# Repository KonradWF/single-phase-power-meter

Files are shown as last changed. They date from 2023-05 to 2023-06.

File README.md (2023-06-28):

# Single-Phase power meter!

The device is used to measure electric power from a single-phase electrical grid.
The following electrical network parameters can be measured with the device:
* Voltage V
* Current I
* Power P
* Reactive Power Q
* Apparent Power S
* Power Factor PF

## Authors 
- Konrad Fiałkowski
- Michał Krzyworzeka
- Bartłomiej Paluch

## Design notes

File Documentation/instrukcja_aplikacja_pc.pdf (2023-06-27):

Metodyki projektowania i modelowania systemów 1 Instrukcja obsługi aplikacji PC MIERNIK MOCY I LICZNIK ENERGII Z KOMUNIKACJĄ USB

Po uruchomieniu aplikacji odtworzy się okienko przedstawione poniżej na rysunku 1. W chwili, gdy aplikacja nie jest połączona z urządzeniem, przy mierzonych parametrach zostanie ukazany napis „b/d”, który wskaże, że nie zostały dostarczone żadne dane. W tym samym czasie na wykresie mocy od czasu pokazywana będzie wartość 0 W.

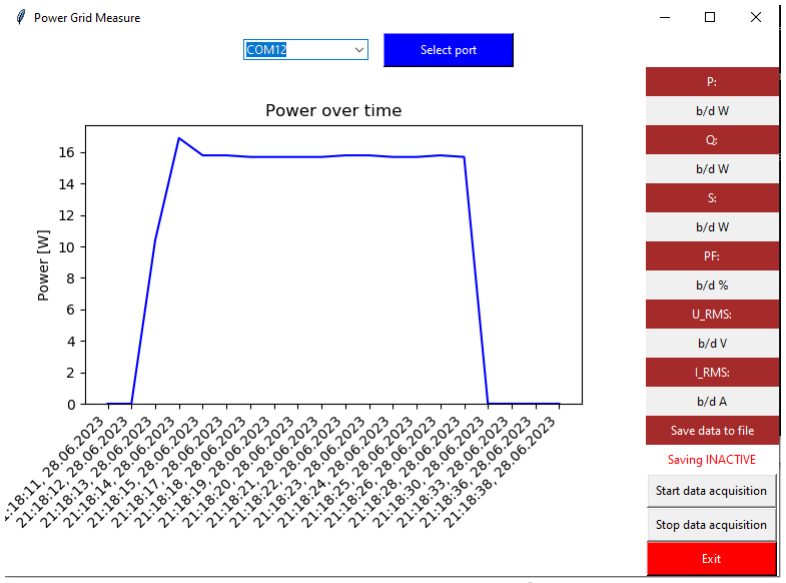
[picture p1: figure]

W celu połączenia aplikacji z urządzeniem, należy wybrać w okienku wyboru w górnej części aplikacji odpowiedni port z listy (przedstawiona na rysunku 2.), do którego podpięty jest miernik mocy. Oznaczenie portu w systemie Windows można sprawdzić w Menedżerze urządzeń w zakładce Porty (COM i LPT). Po wybraniu portu, należy wcisnąć niebieski przycisk „Select port”.

Rysunek 2. Okienko
wyboru portów.

Rysunek 1. Okienko aplikacji po uruchomieniu - brak połączenia z urządzeniem.

Po połączeniu aplikacji z miernikiem, w prawej części zostaną wyświetlone mierzone parametry. Na wykresie mocy czynnej od czasu będzie wykreślana ta zależność. Okienko aplikacji po podłączeniu do urządzenia zostało ukazane na rysunku 3.

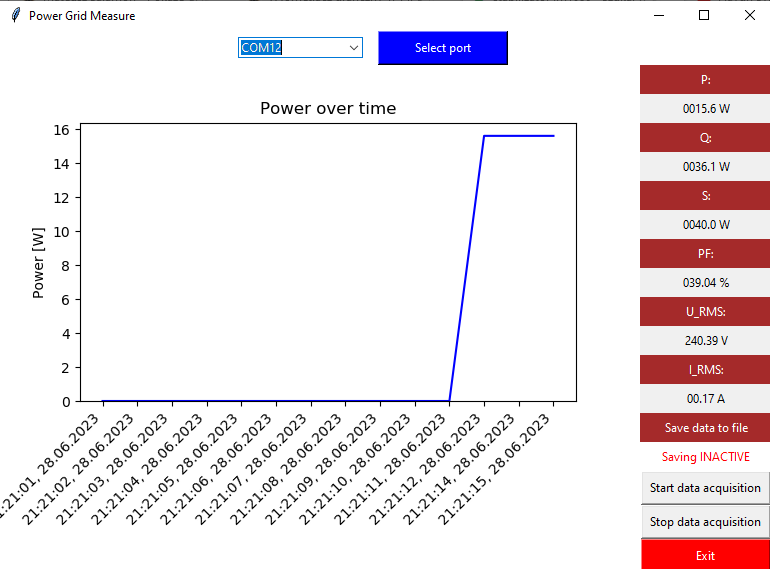
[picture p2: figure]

Rysunek 3. Okienko aplikacji po połączeniu z miernikiem mocy.

Mierzone dane można zapisać do pliku. W tym celu należy wcisnąć przycisk „Start data acquisition” – powyżej czerwony napis „Saving INACTIVE” (jak na rysunku 3.) powinien zamienić się na zielony napis „Saving ACTIVE” (przedstawiony na rysunku 4.).
Po wciśnięciu przycisku „Start data acquisition” utworzy się nowy plik z datą rozpoczęcia zapisu mierzonych parametrów. By przerwać zapis danych do pliku, należy wcisnąć przycisk „Stop data acquisition” – pojawi się z powrotem czerwony napis „Saving INACTIVE”.

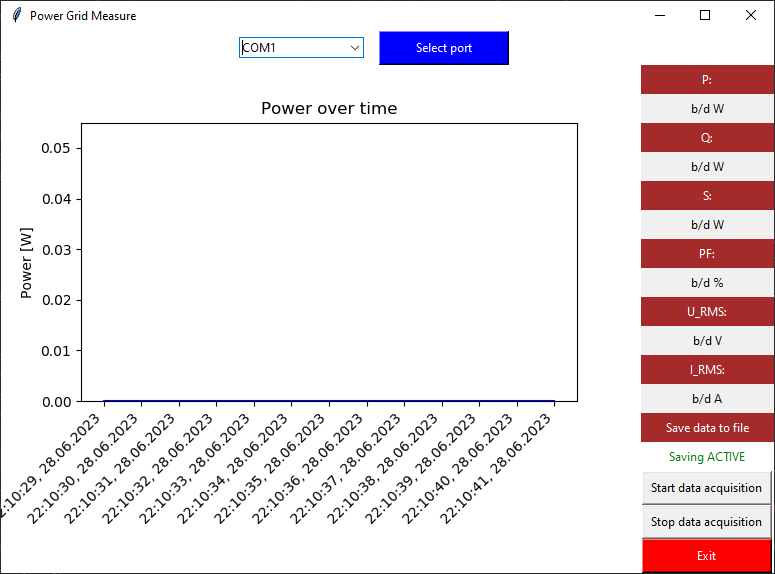
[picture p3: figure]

Rysunek 4. Zapis mierzonych parametrów do pliku - informacja o zapisie.

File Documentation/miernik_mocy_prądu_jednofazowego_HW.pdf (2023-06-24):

Metodyki projektowania i modelowania systemów 1 Dokumentacja projektu - hardware MIERNIK MOCY I LICZNIK ENERGII Z KOMUNIKACJĄ USB

1) Założenia funkcjonalne projektu:

Urządzenie ma umożliwić pomiar wejściowych wielkości elektrycznych urządzeń zasilanych z jednofazowej sieci elektroenergetycznej o napięciu skutecznym 230V.
Dzięki komunikacji USB wyniki pomiarów mogą być zapisywane i przetwarzane na komputerze.
2) Rozeznanie rynku rozwiązań komercyjnych – ceny i funkcjonalność:

Na rynku dostępne są urządzenia o podobnej funkcjonalności do zastosowań laboratoryjnych, przemysłowych jaki i domowych.
W przypadku urządzeń dedykowanych gospodarstwom domowym, mających zwykle postać nakładki na gniazdo funkcjami są pomiar napięcia, prądu, mocy, energii, czasem także częstotliwości i współczynnika mocy (cosφ). Deklarowana dokładność pomiaru to 1%, a maksymalna moc mierzona to 3,6kW. Koszty takich urządzeń zaczynają się od około 60zł.
Urządzenia dla przemysłu mają postać modułów do montażu w rozdzielniach na szynach DIN lub są przystosowane do zabudowy na panelach sterowania lub drzwiach szaf sterowniczych. Funkcjonalność jest podobna jak w przypadku produktów dla gospodarstw domowych, ale zakres pomiaru zwykle jest szerszy, występują też urządzenia przystosowane do współpracy z siecią trójfazową. Koszty najprostszych rozwiązań są podobne jak w przypadku mierników dla gospodarstw domowych.
Kolejną grupą są przyrządy laboratoryjne, oferujące porównywalne
z przemysłowymi zakresy pomiarowe, ale znacznie wyższą dokładność sięgającą 0,1%. Ceny tych urządzeń zaczynają się od kilkuset złotych.
3) Koncepcja rozwiązania:
a) parametry:
- Zakres pomiaru napięcia – 0-230VAC (jeśli zasilanie z innego źródła)
- Zakres pomiaru napięcia – 230VAC±10% (jeśli zasilanie z mierzonego źródła)
- Zakres pomiaru prądu – 0-10AAC
- Pomiar mocy, energii oraz współczynnika mocy
- Separacja galwaniczna zasilania i obwodów wejściowych od układu mikroprocesora
- wyświetlacz OLED
- komunikacja USB dodatkowo separowana dedykowanym układem

b) schemat blokowy

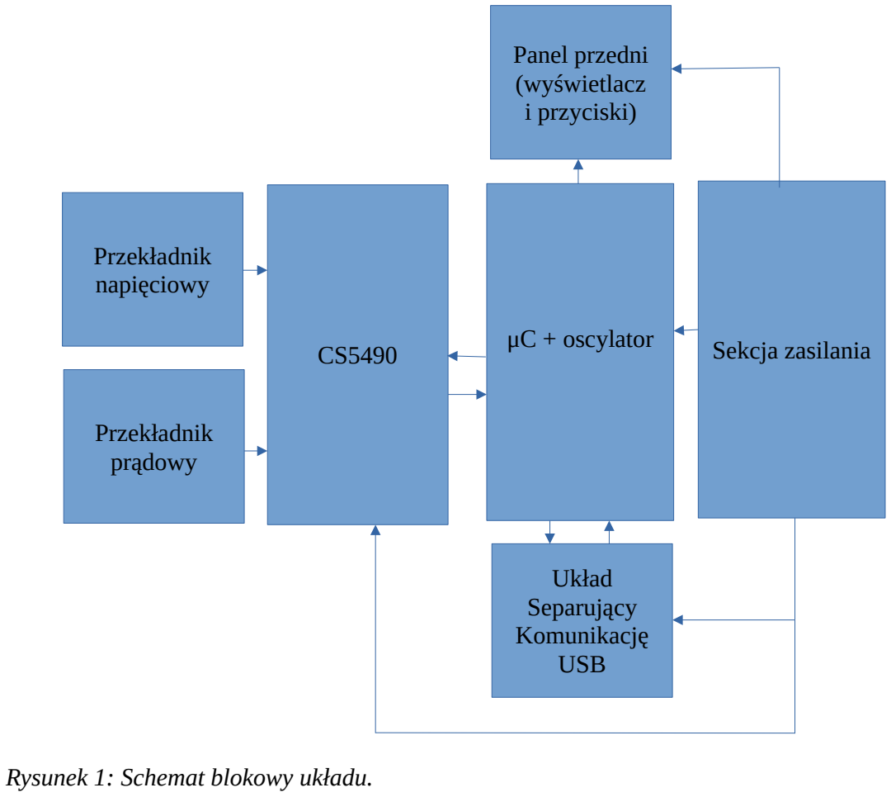
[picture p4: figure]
Rysunek 1: Schemat blokowy układu.; Przekładnik napięciowy; Przekładnik prądowy; Panel przedni (wyświetlacz i przyciski); Układ Separujący Komunikację USB; μC + oscylator; Sekcja zasilania

c) dobór elementów
- Przekładnik napięciowy
Został zastosowany przekładnik napięciowy w postaci transformatora
o przekładni 1:1 (TV19E firmy YHDC) i dzielnik rezystancyjny proponowany przez notę aplikacyjną układu do pomiaru mocy. Rozwiązanie takie zapewnia separacje galwaniczną.
- Przekładnik prądowy
Został zastosowany uniwersalny przekładnik prądowy 20A/0,1A (TAZ14-400 firmy YHDC) a do jego wyjścia został podłączony dzielnik rezystancyjny zapewniający nominalne obciążenie strony wtórnej przekładnika.
- Układ pomiaru mocy
Do pomiary mocy zastosowany został specjalizowany układ Cirrus Logic CS5490, który od strony wejściowej zostanie podłączony do przekładników prądowego i napięciowego przez odpowiednie dzielniki rezystancyjne
i pojemnościowe, a z mikrokontrolerem skomunikuje się przez UART.
- Układ separujący USB

Mimo, że przekładniki prądowe zapewniają separację galwaniczną od sieci dla dodatkowego bezpieczeństwa transmisja USB jest dodatkowo odseparowana galwanicznie, za pomocą układu ADUM3160.
- Wyświetlacz
Wyświetlacz nie jest konieczny do działania urządzenia, transmisja danych przez USB może być wystarczająca, ale zastosowanie ekranu może usprawnić prace z urządzeniem w pewnych sytuacjach. Ze względu na dostępność i optymalizację kosztową zastosowany został wyświetlacz GMT130-v0.1.
- Mikrokontroler
Mikrokontroler musiał spełnić następujące warunki:
-zasilanie 3,3V
-wbudowany RTC
-interface USB
-interface UART
-interface I²C
-interface SPI
-piny GPIO do podłączenia przycisków
Taką specyfikację spełnia kilka kontrolerów z rodziny ATXmega oraz STM32, ale ze względu na aktualną dostępność wybrano STM32F103C8T6
- Sekcja zasilania
Sekcja zasilania została oparta o transformator, w celu zapewnienia maksymalnego bezpieczeństwa i niezawodności układu jak również niskiego poziomu szumów w liniach zasilających. Obniżone napięcie jest prostowane pełnookresowo, odfiltrowane i stabilizowane regulatorem liniowym. Wybrano transformator sieciowy firmy Breve o oznaczeniu katalogowym TEZ6,0/D 230/7,5V.
Zastosowany jest stabilizator liniowy napięcia 3,3V, ze względu na pobór prądu elementów urządzenia jego wydajność prądowa musi wynosić co najmniej 500mA. Takie warunki z zapasem spełnił LM1086-3,3 firmy Texas Instruments.

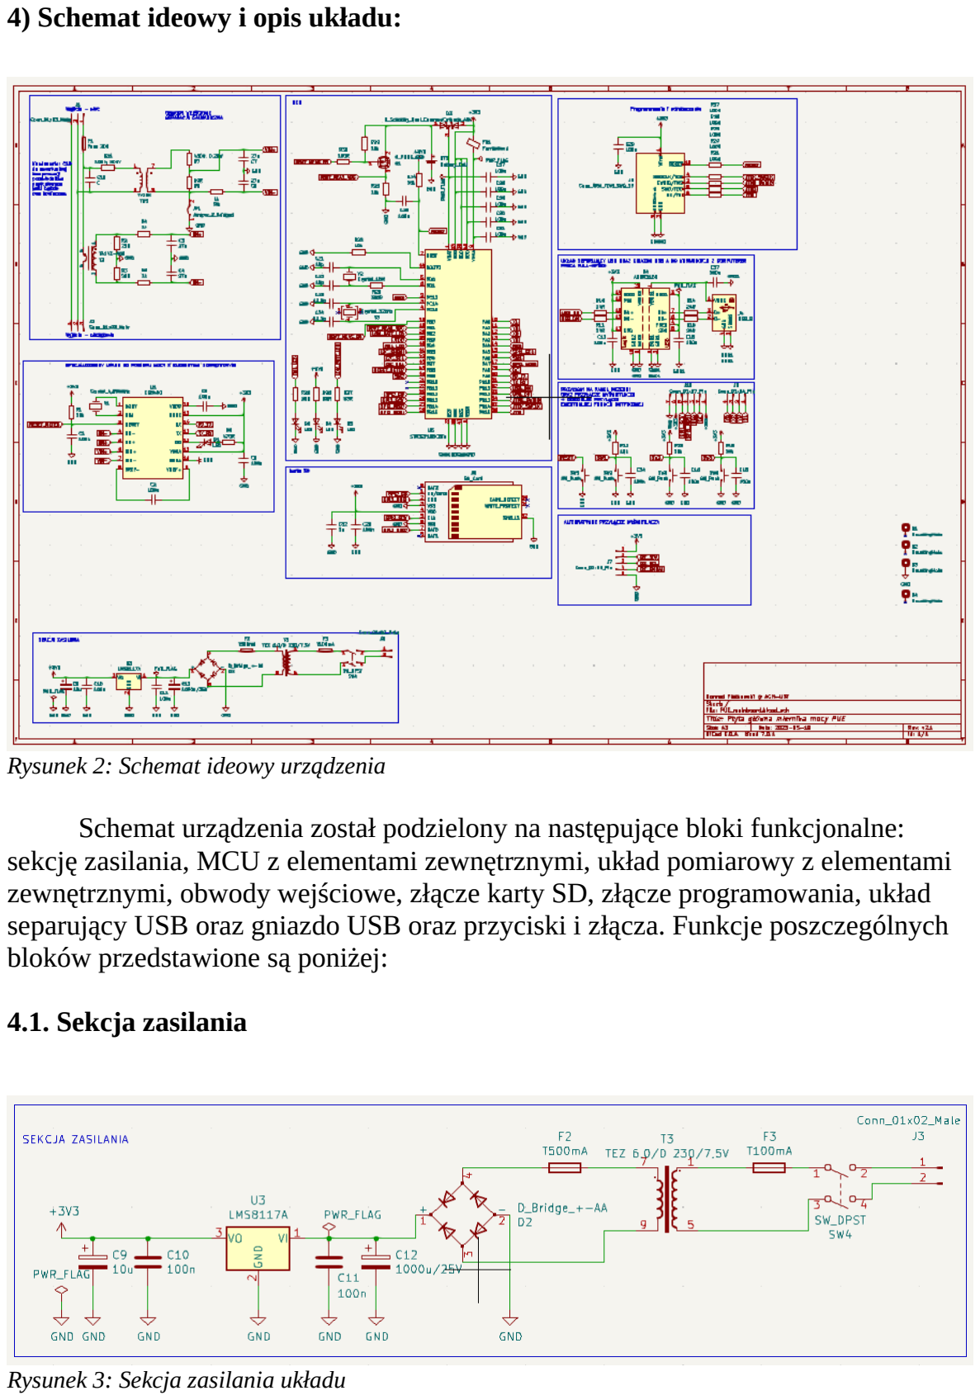
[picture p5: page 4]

4) Schemat ideowy i opis układu:

Schemat urządzenia został podzielony na następujące bloki funkcjonalne: sekcję zasilania, MCU z elementami zewnętrznymi, układ pomiarowy z elementami zewnętrznymi, obwody wejściowe, złącze karty SD, złącze programowania, układ separujący USB oraz gniazdo USB oraz przyciski i złącza. Funkcje poszczególnych bloków przedstawione są poniżej:

### 4.1. Sekcja zasilania

Rysunek 2: Schemat ideowy urządzenia

Rysunek 3: Sekcja zasilania układu

Zasilacz urządzenia jest przedstawieniowy na rysunku 3. Jest to typowy zasilacz transformatorowy z mostkiem Gretza i stabilizatorem liniowym. Zapewnia on separację galwaniczną, dużą niezawodność oraz niski poziom szumów. Dodatkowo takie rozwiązanie jest znacznie szybsze w projektowaniu niż przetwornica.

### 4.2. Obwody wejściowe

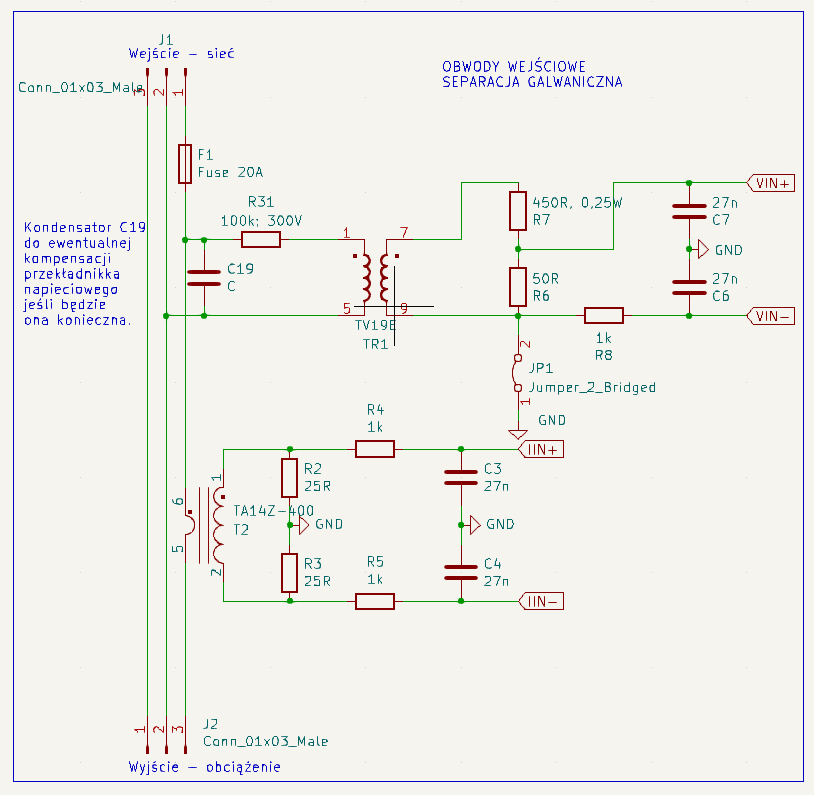
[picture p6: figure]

Obwody wejściowe (Rysunek 4) miernika wzorowane są na nocie katalogowej układu CS5490 i składają się z bezpiecznika, przekładników prądowego i napięciowego oraz zespołu dzielników napięć. Kondycjonowane za ich pomocą sygnały proporcjonalne do mierzonego prądu i napięcia są podawane bezpośrednio na wejścia układu CS5490.

Rysunek 4: Obwody wejściowe miernika

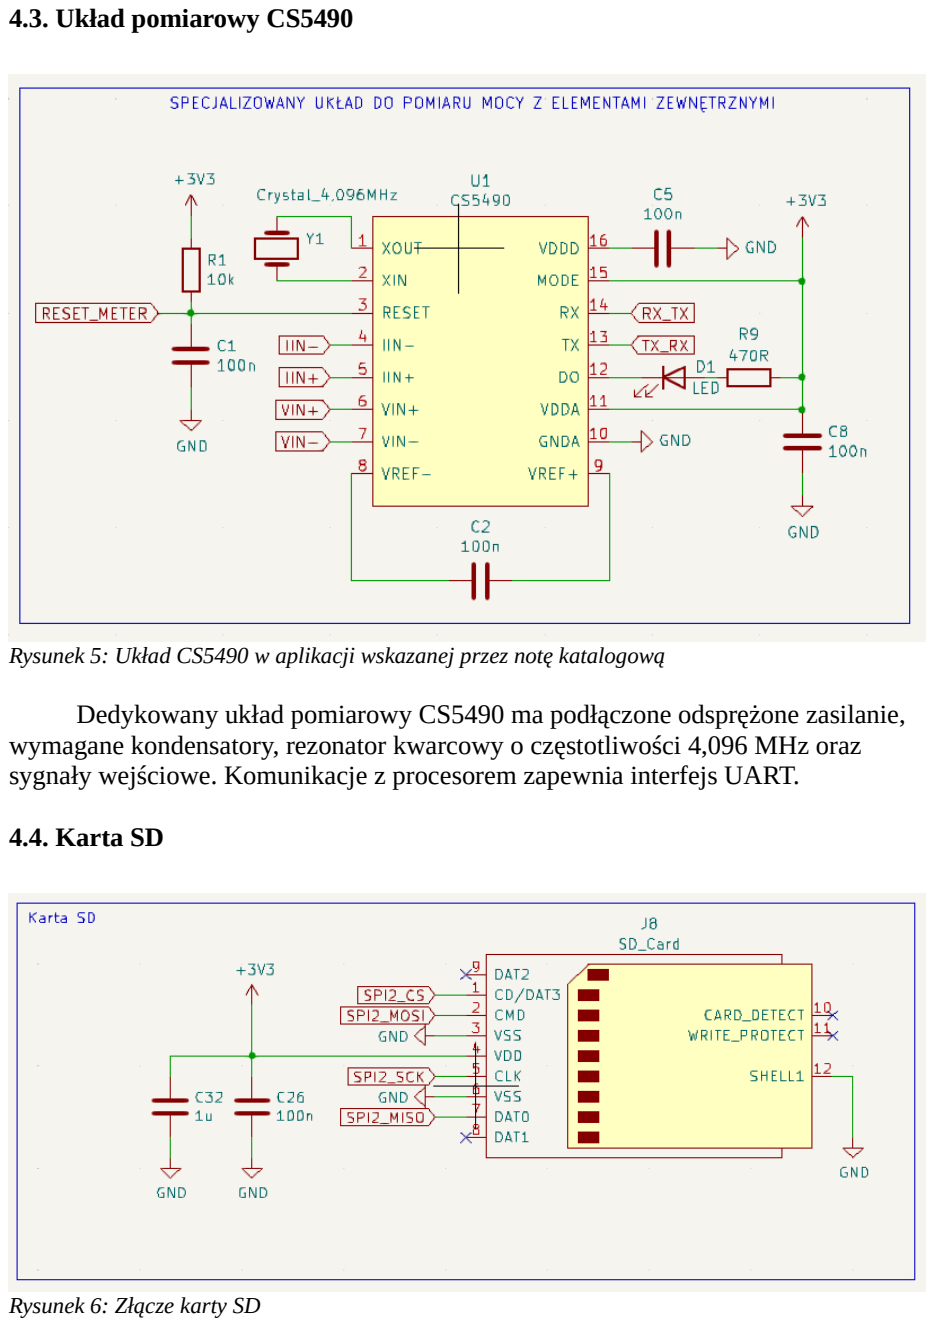
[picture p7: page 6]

### 4.3. Układ pomiarowy CS5490

Dedykowany układ pomiarowy CS5490 ma podłączone odsprężone zasilanie, wymagane kondensatory, rezonator kwarcowy o częstotliwości 4,096 MHz oraz sygnały wejściowe. Komunikacje z procesorem zapewnia interfejs UART.

### 4.4. Karta SD

Rysunek 5: Układ CS5490 w aplikacji wskazanej przez notę katalogową

Rysunek 6: Złącze karty SD

Przedstawione na Rysunku 6 złącze karty SD wraz z kondensatorami odsprzedającymi jej zasilanie umożliwia wykorzystanie urządzenia do akwizycji danych bez współpracy z komputerem.

### 4.5. Mikrokontroler i wymagane elementy zewnętrzne

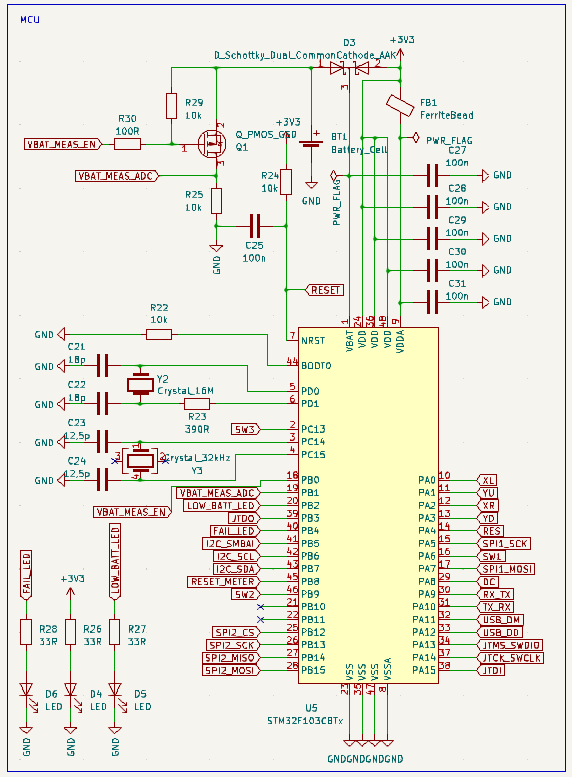
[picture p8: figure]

Rysunek 7: Mikrokontroler STM32F103C8T6, diody sygnalizacyjne oraz niezbędne elementy zewnętrzne

Pracą miernika steruje mikrokontroler STM32F103C8T6. Pracuje on z zewnętrznym rezonatorem kwarcowym 16 MHz. Zastosowano także rezonator 32,768 kHz potrzebny do pracy zegara czasu rzeczywistego stosowanego przy zapisywaniu parametrów sieci w czasie na kartę SD. Zegar czasu rzeczywistego ma podtrzymanie zapewniane przez baterię o napięciu 3 V. W tym bloku funkcjonalnym znajduje się też układ pozwalający na mierzenie napięcia tej baterii. Jest on załączany tranzystorem, co zapobiega rozładowywaniu baterii w czasie, gdy nie jest ona mierzona.

### 4.6. Złącze JTAG/SWD

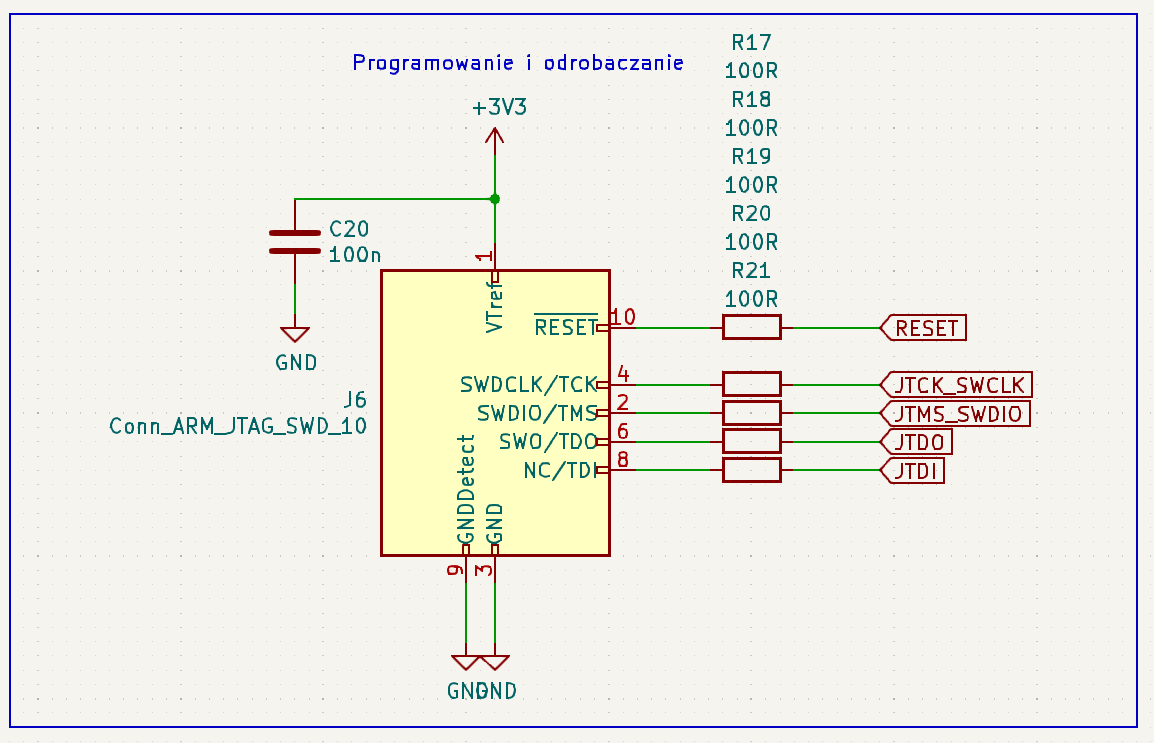
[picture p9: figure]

W celu zaprogramowania mikroprocesora w przyrządzie pomiarowym należy do złącza J6 (Rysunek 8) podłączyć programator zgodny ze standardem JTAG albo SWD. Linie zrgnałowe zostały zabezpieczone rezystorami o wartości 100 Ω co zmniejsza szanse uszkodzenia układu w przypadku użycia wadliwej przejściówki.

Rysunek 8: Złącze do programowania i debugowania kodu urządzenia.

### 4.7. Układ separujący komunikację USB

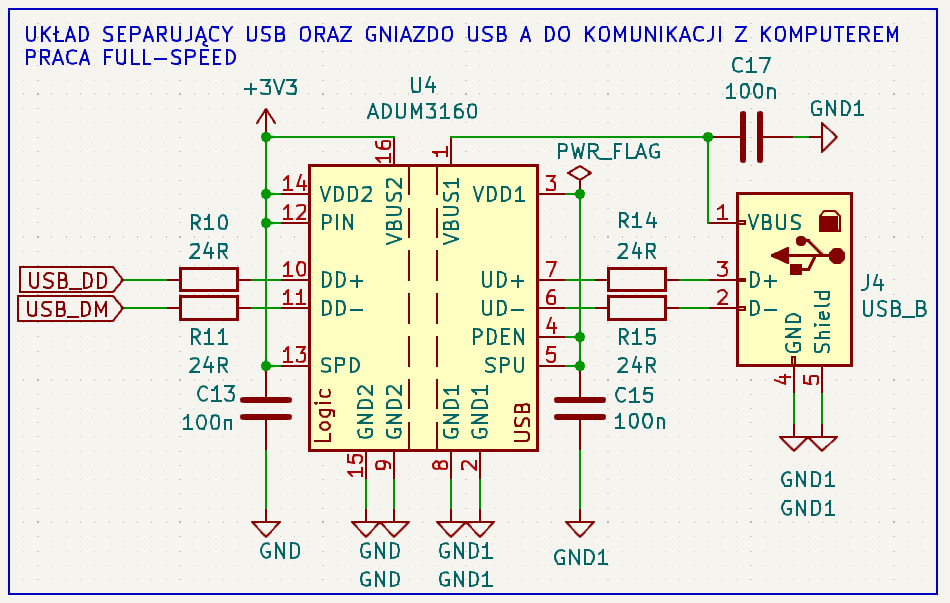
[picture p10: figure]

Aby zapewnić jak największe bezpieczeństwo użytkowania układu przy współpracy z komputerem PC komunikacja przez USB została odseparowana galwanicznie dedykowanym układem scalonym ADUM3160. Układ jest połączony w konfiguracji zalecanej przez notę katalogową.

### 4.8. Złącza i przyciski

Do obsługi urządzenia przeznaczone są cztery przyciski (jeden z nich to RESET, pozostałe służą od obsługi menu). Ponadto z płyty głównej wyprowadzone jest złącze magistrali SPI i zasilania do wyświetlacza, alternatywne złącze do ekranu z magistralą I²C i zasilaniem. Dodatkowo zostało wyprowadzone złącze do obsługi funkcji wyświetlacza dotykowego.

Rysunek 9: Układ separujący galwanicznie komunikację USB wraz z elementami zewnętrznymi.

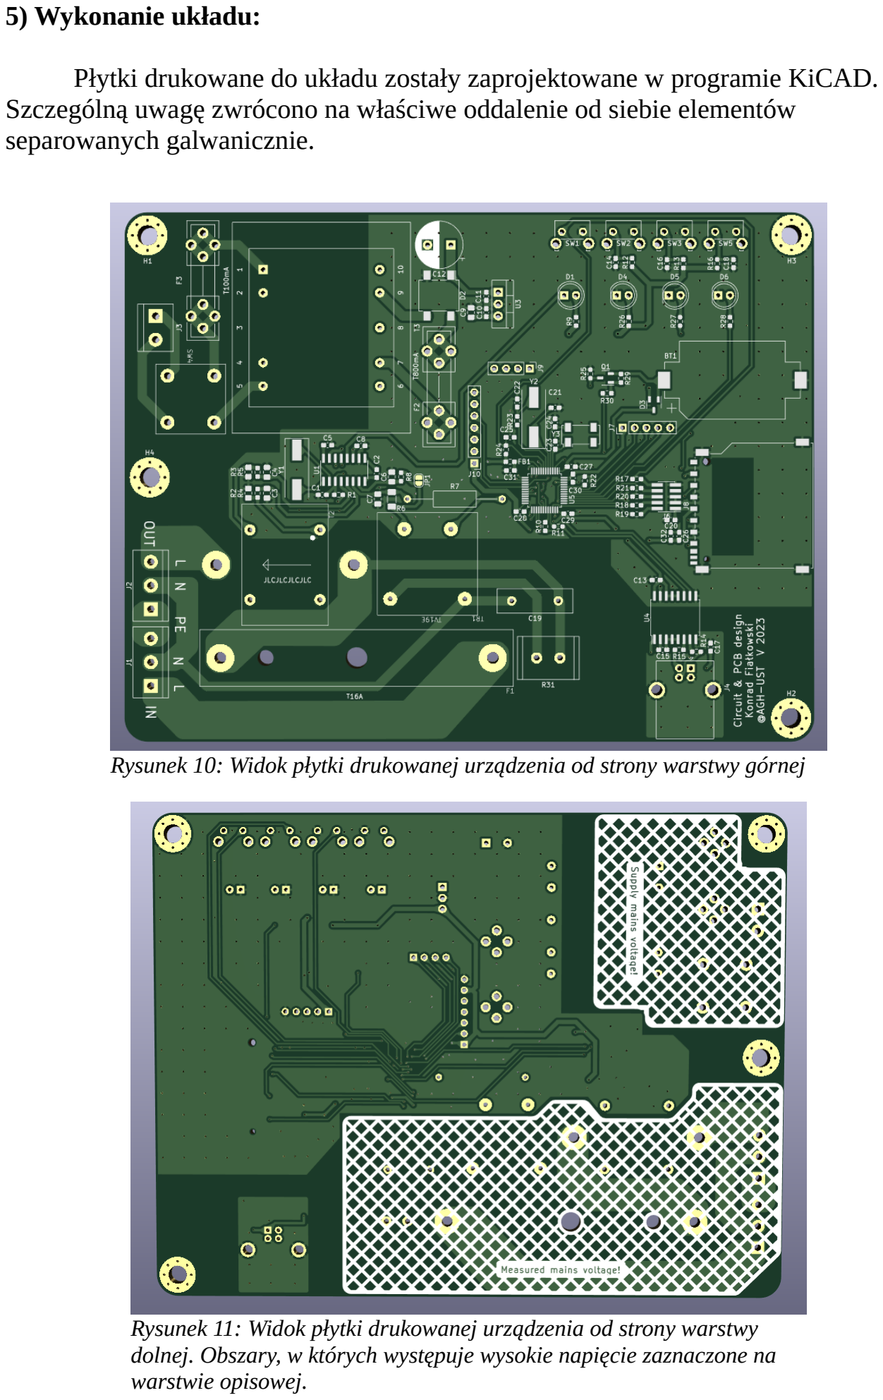
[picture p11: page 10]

5) Wykonanie układu:

Płytki drukowane do układu zostały zaprojektowane w programie KiCAD. Szczególną uwagę zwrócono na właściwe oddalenie od siebie elementów separowanych galwanicznie.

Rysunek 10: Widok płytki drukowanej urządzenia od strony warstwy górnej

Rysunek 11: Widok płytki drukowanej urządzenia od strony warstwy dolnej. Obszary, w których występuje wysokie napięcie zaznaczone na warstwie opisowej.

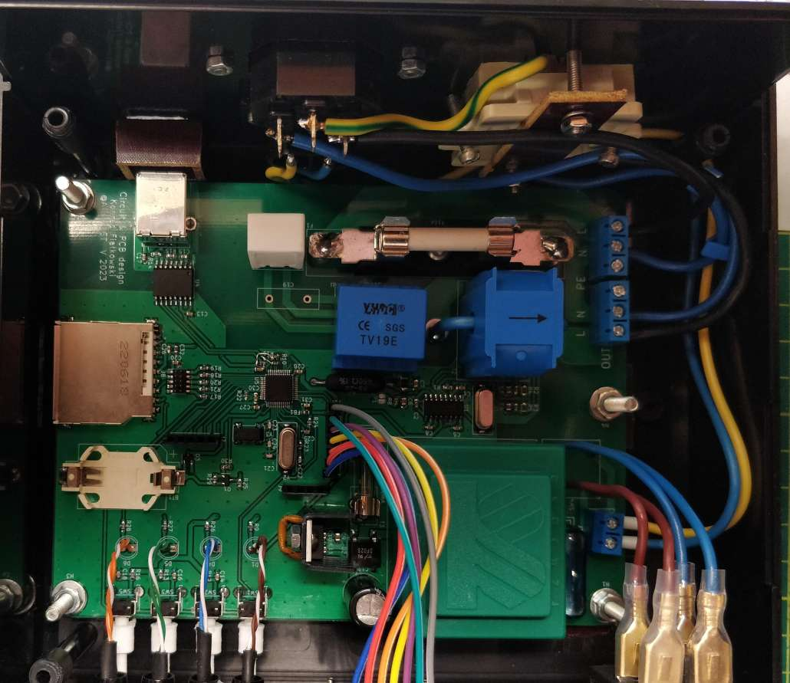
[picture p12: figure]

8) Podsumowanie :

Projekt urządzenia wykonano w oparciu o noty katalogowe zastosowanych układów scalonych, oraz opisy techniczne dostępnych komercyjnie przyrządów.
Po wgraniu odpowiedniego oprogramowania i współczynników kalibracyjnych układ działa poprawnie. W kolejnej rewizji można by opracować bardziej energooszczędny układ zasilania, ekranowanie toru pomiarowego oraz usunąć drobne wady zauważone podczas uruchamiania projektu.

Rysunek 12: Widok zmontowanej płytki drukowanej urządzenia zamontowanej w obudowie

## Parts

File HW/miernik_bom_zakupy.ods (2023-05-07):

Source: | D:\Elektronika\PUE_mainboard\PUE_mainboard.kicad_sch |  |  |  |  | czy zgodne z iloscią?
Date: | 14.04.2023 17:34:17
Tool: | Eeschema 7.0.1
Generator: | D:\KiCAD_7\7.0\bin\scripting\plugins/bom_csv_grouped_by_value.py
Component Count: | 98
Collated Components:
Item | Qty | Reference(s) | Value |  |  |  | DNP
1 | 1 | BT1 | Battery_Cell | https://www.tme.eu/pl/details/ch28-2032/baterie-pojemniki-i-uchwyty/comf/ch28-2032lf/ | https://www.mouser.pl/ProductDetail/Renata/SMTU2032-C?qs=UxeAxwACbqkmlMDdDbz%2FoA%3D%3D | x
2 | 20 | C1, C2, C5, C8, C10, C11, C13, C14, C15, C16, C17, C18, C20, C25, C26, C27, C28, C29, C30, C31 | 100n | https://www.tme.eu/pl/details/0603yc104kat2a/kondensatory-mlcc-smd/kyocera-avx/ | https://www.mouser.pl/ProductDetail/YAGEO/CC0603JRX7R8BB104?qs=5q%252BqlK8CmJTEpQNLR3WZPw%3D%3D | x
3 | 4 | C3, C4, C6, C7 | 27n | https://www.tme.eu/pl/details/c0603c273k5rac/kondensatory-mlcc-smd/kemet/c0603c273k5ractu/ | https://www.mouser.pl/ProductDetail/KEMET/C0805C273J3GACTU?qs=oww1zRtU%252Bv2SG5P1%2FHn6gQ%3D%3D | x
4 | 1 | C9 | 10u | https://www.tme.eu/pl/details/grm188z71a106ka73d/kondensatory-mlcc-smd/murata/ | https://www.mouser.pl/ProductDetail/Samsung-Electro-Mechanics/CL21B106KOQNNNE?qs=349EhDEZ59r8qgLddyW2Yw%3D%3D | x
5 | 1 | C12 | 1000u/25V | https://www.tme.eu/pl/details/ucd1e102mnq1ms/kondensatory-elektrolityczne-smd/nichicon/ | https://www.mouser.pl/ProductDetail/Panasonic/EEU-FR1E102E?qs=zR1FDKe%2FpuBUNZowDH12Tw%3D%3D | x
6 | 1 | C19 | C | nie montować
7 | 2 | C21, C22 | 18p | https://www.tme.eu/pl/details/vj0402a180jxjcw1bc/kondensatory-mlcc-smd/vishay/ | https://www.mouser.pl/ProductDetail/KYOCERA-AVX/02013A180GAT2A?qs=xoLhGqqHLYBbnRIqdpEZPg%3D%3D | x
8 | 2 | C23, C24 | 12,5p | https://www.tme.eu/pl/details/04025a120jat2a/kondensatory-mlcc-smd/kyocera-avx/ | https://www.mouser.pl/ProductDetail/Murata-Electronics/GCM1885C2A120GA16D?qs=QzBtWTOodeVSlFS21Kh%2F4w%3D%3D | x
9 | 1 | C32 | 1u | https://www.tme.eu/pl/details/c0603c105k3rac/kondensatory-mlcc-smd/kemet/c0603c105k3ractu/ | https://www.mouser.pl/ProductDetail/KYOCERA-AVX/0603YC105KAT2A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 | x
10 | 4 | D1, D4, D5, D6 | LED | https://www.tme.eu/pl/details/fyl-5013gd1c/diody-led-tht-okragle/foryard/ | https://www.mouser.pl/ProductDetail/Cree-LED/C566D-GFE-CY0Z0792?qs=7D1LtPJG0i2HFf%2FmrtSWoA%3D%3D | x
11 | 1 | D2 | D_Bridge_+-AA | mam w gratach
12 | 1 | D3 | D_Schottky_Dual_CommonCathode_AAK | https://www.tme.eu/pl/details/bat54c.215/diody-schottky-smd/nexperia/bat54c-215/ | https://www.mouser.pl/ProductDetail/onsemi/BAT54CLT1G?qs=vLkC5FC1VN%252BEteCXar4p7g%3D%3D | x
13 | 1 | F1 | Fuse 20A | https://www.tme.eu/pl/details/8040.0001/gniazda-bezpiecznikowe-pcb/schurter/ | https://www.mouser.pl/ProductDetail/Bussmann-Eaton/BK2-S-4201-1-R?qs=DRkmTr78QASEegk7bdGxSw%3D%3D | x
14 | 1 | F2 | T500mA | mam w gratach
15 | 1 | F3 | T100mA | mam w gratach
16 | 1 | FB1 | FerriteBead | https://www.tme.eu/pl/details/z0603c330apmst/ferryty-koraliki/kemet/ | https://www.mouser.pl/ProductDetail/Wurth-Elektronik/7426926222?qs=amGC7iS6iy9ALkZWEWd9eQ%3D%3D | x
17 | 2 | J1, J2 | Conn_01x03_Male | mam w gratach
18 | 1 | J4 | USB_B | https://www.tme.eu/pl/details/tueb4f2d0b/zlacza-usb-i-ieee1394/amphenol-communications-solutions/ | https://www.mouser.pl/ProductDetail/Amphenol-FCI/61729-0010BLF?qs=Lu3apKW7jUhgLQlMxtWsEQ%3D%3D | x
19 | 1 | J5 | Conn_01x02_Male | mam w gratach
20 | 1 | J6 | Conn_ARM_JTAG_SWD_10 | https://www.tme.eu/pl/details/20021221-00010c4lf/listwy-i-gniazda-kolkowe/amphenol-communications-solutions/ | https://www.mouser.pl/ProductDetail/Harwin/M50-3600542R?qs=DVxm2sPGGrrPu%2FxuhpV3yw%3D%3D | x
21 | 1 | J7 | Conn_01x05_Pin | mam w gratach
22 | 1 | J8 | SD_Card | https://www.tme.eu/pl/details/gsd090012seu/zlacza-do-kart/amphenol-communications-solutions/ | https://www.mouser.pl/ProductDetail/Amphenol-Commercial-Products/GSD090012SEU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 | x
23 | 1 | J9 | Conn_01x04_Pin | mam w gratach
24 | 1 | J10 | Conn_01x07_Pin | mam w gratach
25 | 1 | Q1 | Q_PMOS_GSD | https://www.tme.eu/pl/details/dmp2045u-7/tranzystory-z-kanalem-p-smd/diodes-incorporated/ | https://www.mouser.pl/ProductDetail/Diodes-Incorporated/DMP2045U-7?qs=rrS6PyfT74erdUwo5CgHTg%3D%3D | x
26 | 8 | R1, R12, R13, R16, R22, R24, R25, R29 | 10k | https://www.tme.eu/pl/details/wf06p-10k-5%25/rezystory-smd/walsin/wf06p103jtl/ | https://www.mouser.pl/ProductDetail/YAGEO/RC0603FR-0710KL?qs=grNVn54RoB%252B3GtjbJj3wJQ%3D%3D | x
27 | 2 | R2, R3 | 25R | https://www.tme.eu/pl/details/ar0603-22r-0.1%25/rezystory-smd/viking/ar03btcx0220/ | https://www.mouser.pl/ProductDetail/Vishay-Dale/TNPW080524R9BEEA?qs=7mXrnZESPL%2FkAvHc%252BWVVUw%3D%3D | x
28 | 3 | R4, R5, R8 | 1k | https://www.tme.eu/pl/details/wf06p-1k-5%25/rezystory-smd/walsin/wf06p102jtl/ | https://www.mouser.pl/ProductDetail/YAGEO/AC0603FR-071KL?qs=UoPT7wUmgYJx4gI0q%252BcIRQ%3D%3D | x
29 | 1 | R6 | 50R | https://www.tme.eu/pl/details/ar0603-50r-0.1%25/rezystory-smd/viking/ar03btcx0500/ | https://www.mouser.pl/ProductDetail/KOA-Speer/RS73F2BTTD51R0B?qs=YwPsRIUVAOcobtBZ20vHbw%3D%3D | x
30 | 1 | R7 | 450R, 0,25W | https://www.tme.eu/pl/details/era3aeb4530v/rezystory-smd/panasonic/ | https://www.mouser.pl/ProductDetail/Vishay-Dale/RS02B450R0FB12?qs=pklOJxMndox899a6snotSQ%3D%3D | x
31 | 1 | R9 | 470R | https://www.tme.eu/pl/details/wf06p-470r-5%25/rezystory-smd/walsin/wf06p471jtl/ | https://www.mouser.pl/ProductDetail/YAGEO/RC0603FR-07470RL?qs=sGAEpiMZZMtlubZbdhIBIItYu4jZFrq8UR4ecweFqus%3D | x
32 | 4 | R10, R11, R14, R15 | 24R | https://www.tme.eu/pl/details/smd0603-24r-1%25/rezystory-smd/royal-ohm/0603saf240jt5e/ | https://www.mouser.pl/ProductDetail/YAGEO/RC0603FR-0724RL?qs=m6lXFsvg5e04PEGoj4%2FQEQ%3D%3D | x
33 | 6 | R17, R18, R19, R20, R21, R30 | 100R | https://www.tme.eu/pl/details/crgcq0603j100r/rezystory-smd/te-connectivity/1-2176340-3/ | https://www.mouser.pl/ProductDetail/YAGEO/RC0603FR-07100RL?qs=NEN%2FsE%2FLsvPIwIWKCOS4%2FA%3D%3D | x
34 | 1 | R23 | 390R | https://www.tme.eu/pl/details/wf06p-390r-5%25/rezystory-smd/walsin/wf06p391jtl/ | https://www.mouser.pl/ProductDetail/YAGEO/RC0603FR-07390RL | x
35 | 3 | R26, R27, R28 | 33R | https://www.tme.eu/pl/details/wf06p-33r-5%25/rezystory-smd/walsin/wf06p330jtl/ | https://www.mouser.pl/ProductDetail/603-RC0603FR-1033RL | x
36 | 4 | SW1, SW2, SW3, SW5 | SW_Push | https://www.tme.eu/pl/details/b3f-3122/mikroprzelaczniki-tact/omron-ocb/ | https://www.mouser.pl/ProductDetail/TE-Connectivity-PB/1-1825027-7?qs=f77SmbfBTEqvrOH32rsDWQ%3D%3D | x
37 | 1 | SW4 | SW_DPST | mam w gratach
38 | 1 | T1 | TAK12-02 | alledrogo
39 | 1 | T2 | TV19E | alledrogo
40 | 1 | T3 | TEZ 4,0/D 230/7,5V | https://www.tme.eu/pl/details/tszz6_7.5v/transformatory-do-pcb/indel/tszz7-027m/ |  | x
41 | 1 | U1 | CS5490 | https://www.tme.eu/pl/details/cs5490-isz/uklady-scalone-pozostale/cirrus-logic/ | https://www.mouser.pl/ProductDetail/Cirrus-Logic/CS5490-ISZR?qs=jx0ze0HFsp40EUANRwQNqg%3D%3D | x
42 | 1 | U3 | LMS8117A | https://www.tme.eu/pl/details/lm1086it-3.3_nopb/stabilizatory-napiecia-nieregulowane-ldo/texas-instruments/ | https://www.mouser.pl/ProductDetail/Texas-Instruments/LM1086IT-3.3-NOPB?qs=X1J7HmVL2ZES7qSylhrDFg%3D%3D | x
43 | 1 | U4 | ADUM3160 | https://www.tme.eu/pl/details/adum3160brwz-rl/uklady-scalone-interfejsy-pozostale/analog-devices/ | https://www.mouser.pl/ProductDetail/Analog-Devices/ADUM3160BRWZ-RL?qs=WIvQP4zGaniZo3xx1fxm1A%3D%3D | x
44 | 1 | U5 | STM32F103C8Tx | https://www.tme.eu/pl/details/stm32f103c8t6/mikrokontrolery-st/stmicroelectronics/ | https://www.mouser.pl/ProductDetail/STMicroelectronics/STM32F103C8T6?qs=bhCVus9SdFtq6kqxsU5%2FDA%3D%3D | x
45 | 1 | Y1 | Crystal_4,096MHz | https://www.tme.eu/pl/details/4.096m-smdhc49s/rezonatory-kwarcowe-smd/yic/ | https://www.mouser.pl/ProductDetail/ABRACON/ABLS-4.096MHZ-L4Q-T?qs=uDmhV2jwPRc2aCKqIgbi5A%3D%3D | x
46 | 1 | Y2 | Crystal_16M | https://www.tme.eu/pl/details/49s-16.000meej-t/rezonatory-kwarcowe-smd/qst/qt49s-16-000meej-t/ | https://www.mouser.pl/ProductDetail/ECS/ECS-160-18-5PX-GM-TR?qs=amGC7iS6iy9jy4CztfLIlw%3D%3D | x
47 | 1 | Y3 | Crystal_32kHz | https://www.tme.eu/pl/details/32.768khz-mc306/rezonatory-kwarcowe-smd/epson/mc306-32-768000khz-12-5pf/ | https://www.mouser.pl/ProductDetail/ABRACON/ABS25-32.768KHZ-T?qs=2xLVn2jvFusfExB%252ByZEnpA%3D%3D | x
 |  |  | bezpiecznik | https://www.tme.eu/pl/details/ada20a250v/bezpieczniki-6-3x32mm-zwloczne/conquer-electronic-co-ltd/ada-20a-250v/ | https://www.mouser.pl/ProductDetail/Bel-Fuse/3AB-20-R?qs=MvPYbBWWJysdLtZ4sLp34Q%3D%3D | x
 | 2 | Rzeczy Bartka | IDC14 | https://www.tme.eu/pl/details/ds1017-01-14na8/zlacza-idc/connfly/ |  | x
 | 2 |  | listwa goldpin | https://www.tme.eu/pl/details/ph1-40-ua/listwy-i-gniazda-kolkowe/adam-tech/ |  | x
 | 2 | Rzeczy Mariana | akumulator | https://www.tme.eu/pl/details/slb03070lr351bs/akumulatory/nichicon/
 |  |  | BQ25504 |  | https://www.mouser.pl/ProductDetail/?qs=LDM2r2BBpna1ocxRvQkZ2w%3D%3D | x
 |  |  | NEH2000BYJ |  | https://www.mouser.pl/ProductDetail/Nexperia/NEH2000BYJ?qs=Jm2GQyTW%2FbhDO%2FTC72XN%2Fw%3D%3D | x
 |  |  | Z84C0010AEG |  | https://www.mouser.pl/ProductDetail/ZiLOG/Z84C0010AEG?qs=87AjWkFq0r4vnAaeK2Di%2FA%3D%3D | x
 |  | inne moje graty
 |  |  | 4,7uF/400V |  | https://www.mouser.pl/ProductDetail/Nichicon/UVR2G4R7MPD1TD | x
 |  |  | LR44 |  | https://www.mouser.pl/ProductDetail/Murata-Electronics/LR44?qs=l7cgNqFNU1geV71Ob3VhoA%3D%3D | x

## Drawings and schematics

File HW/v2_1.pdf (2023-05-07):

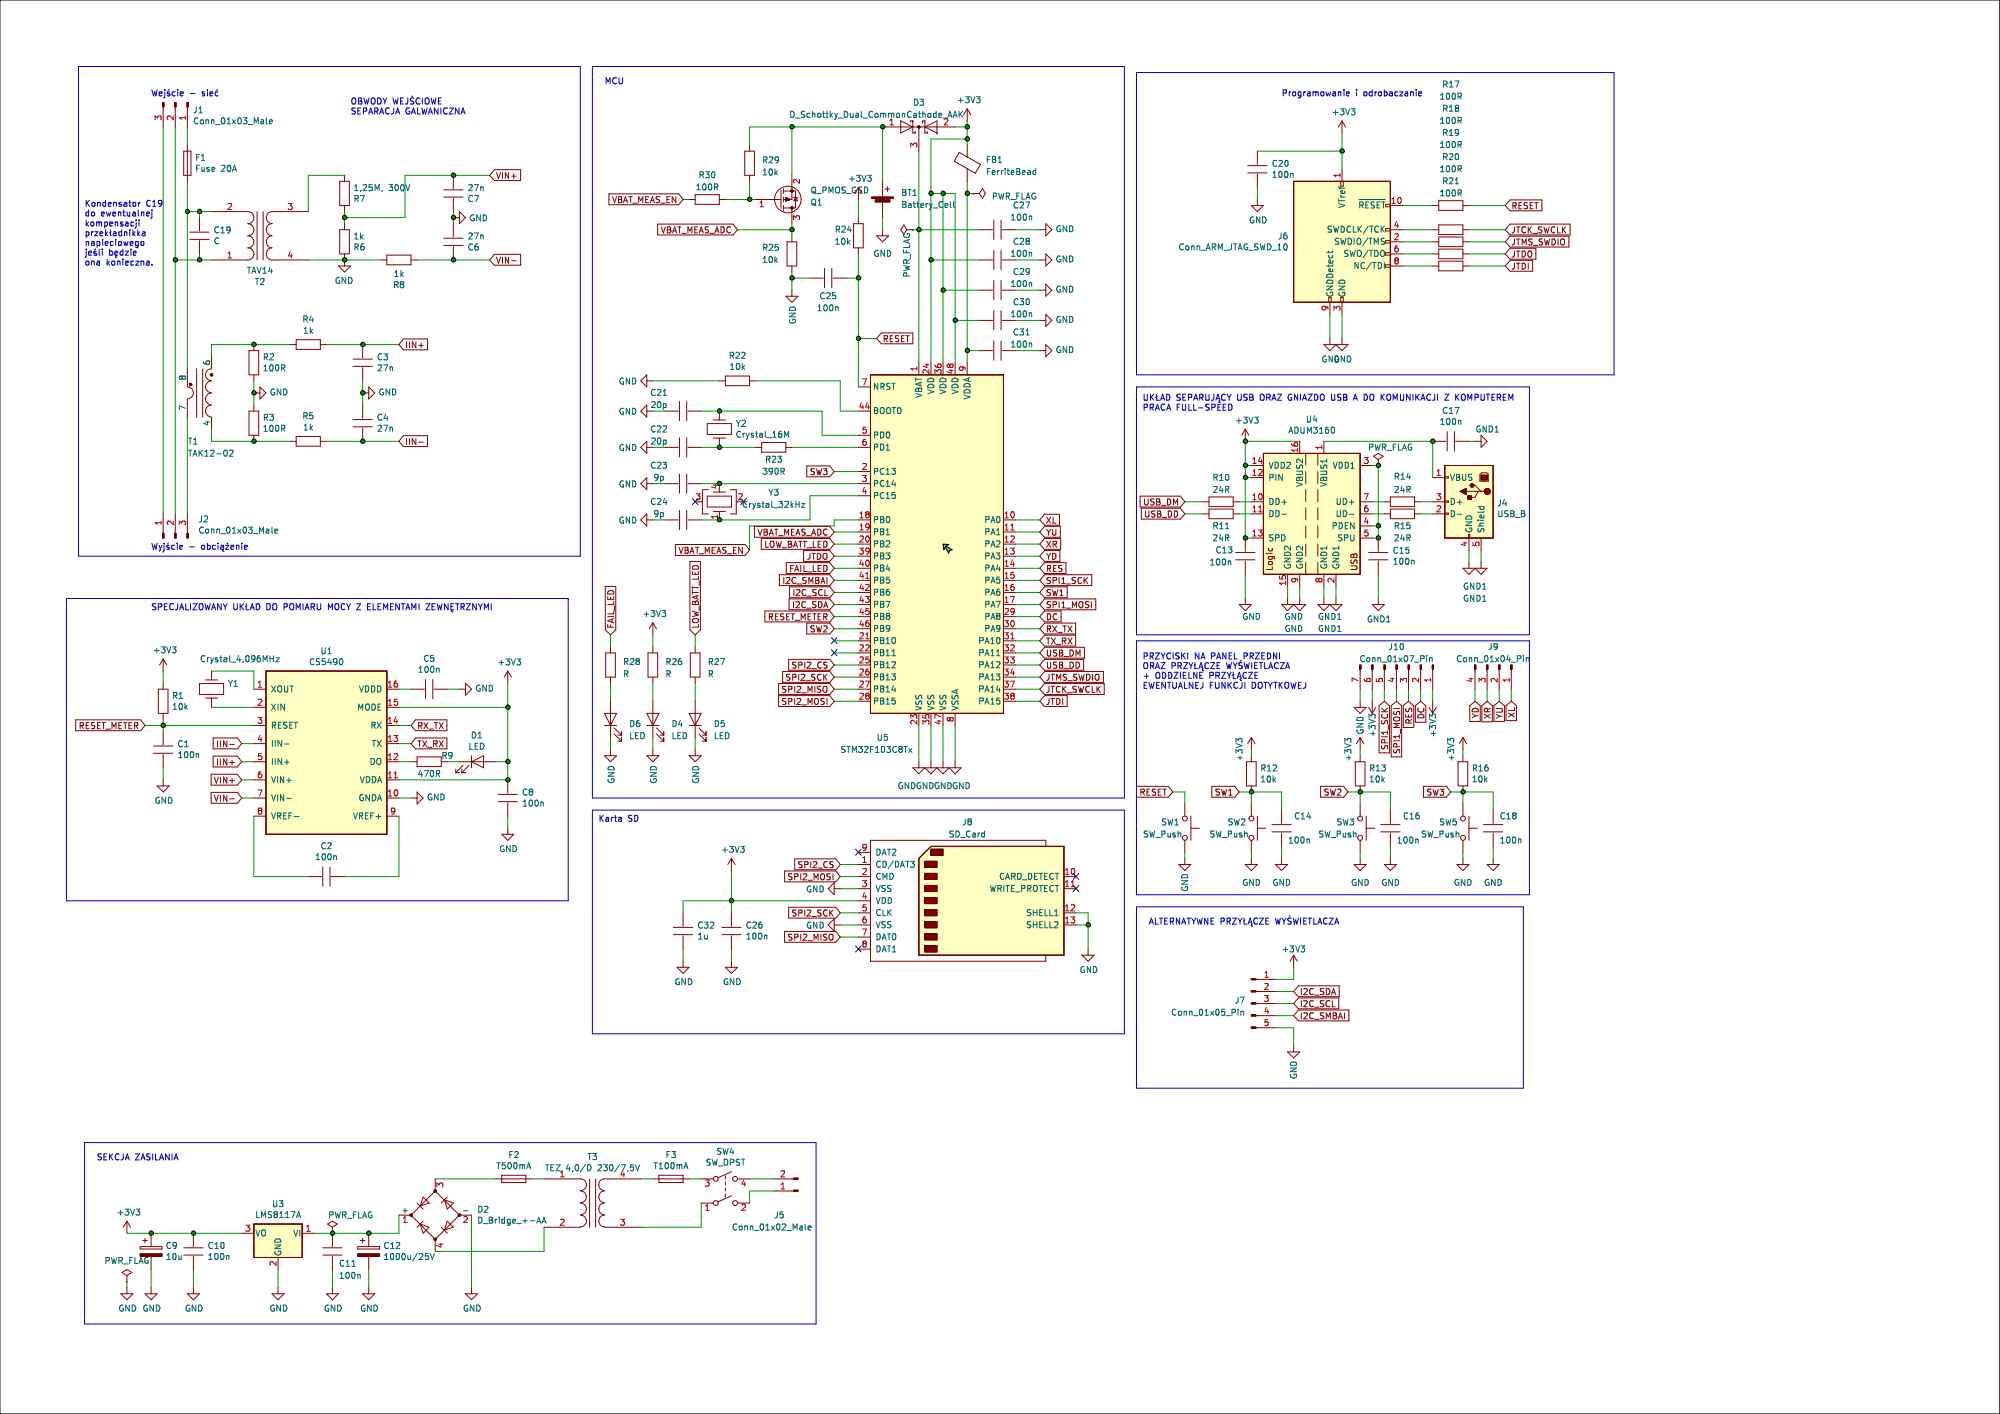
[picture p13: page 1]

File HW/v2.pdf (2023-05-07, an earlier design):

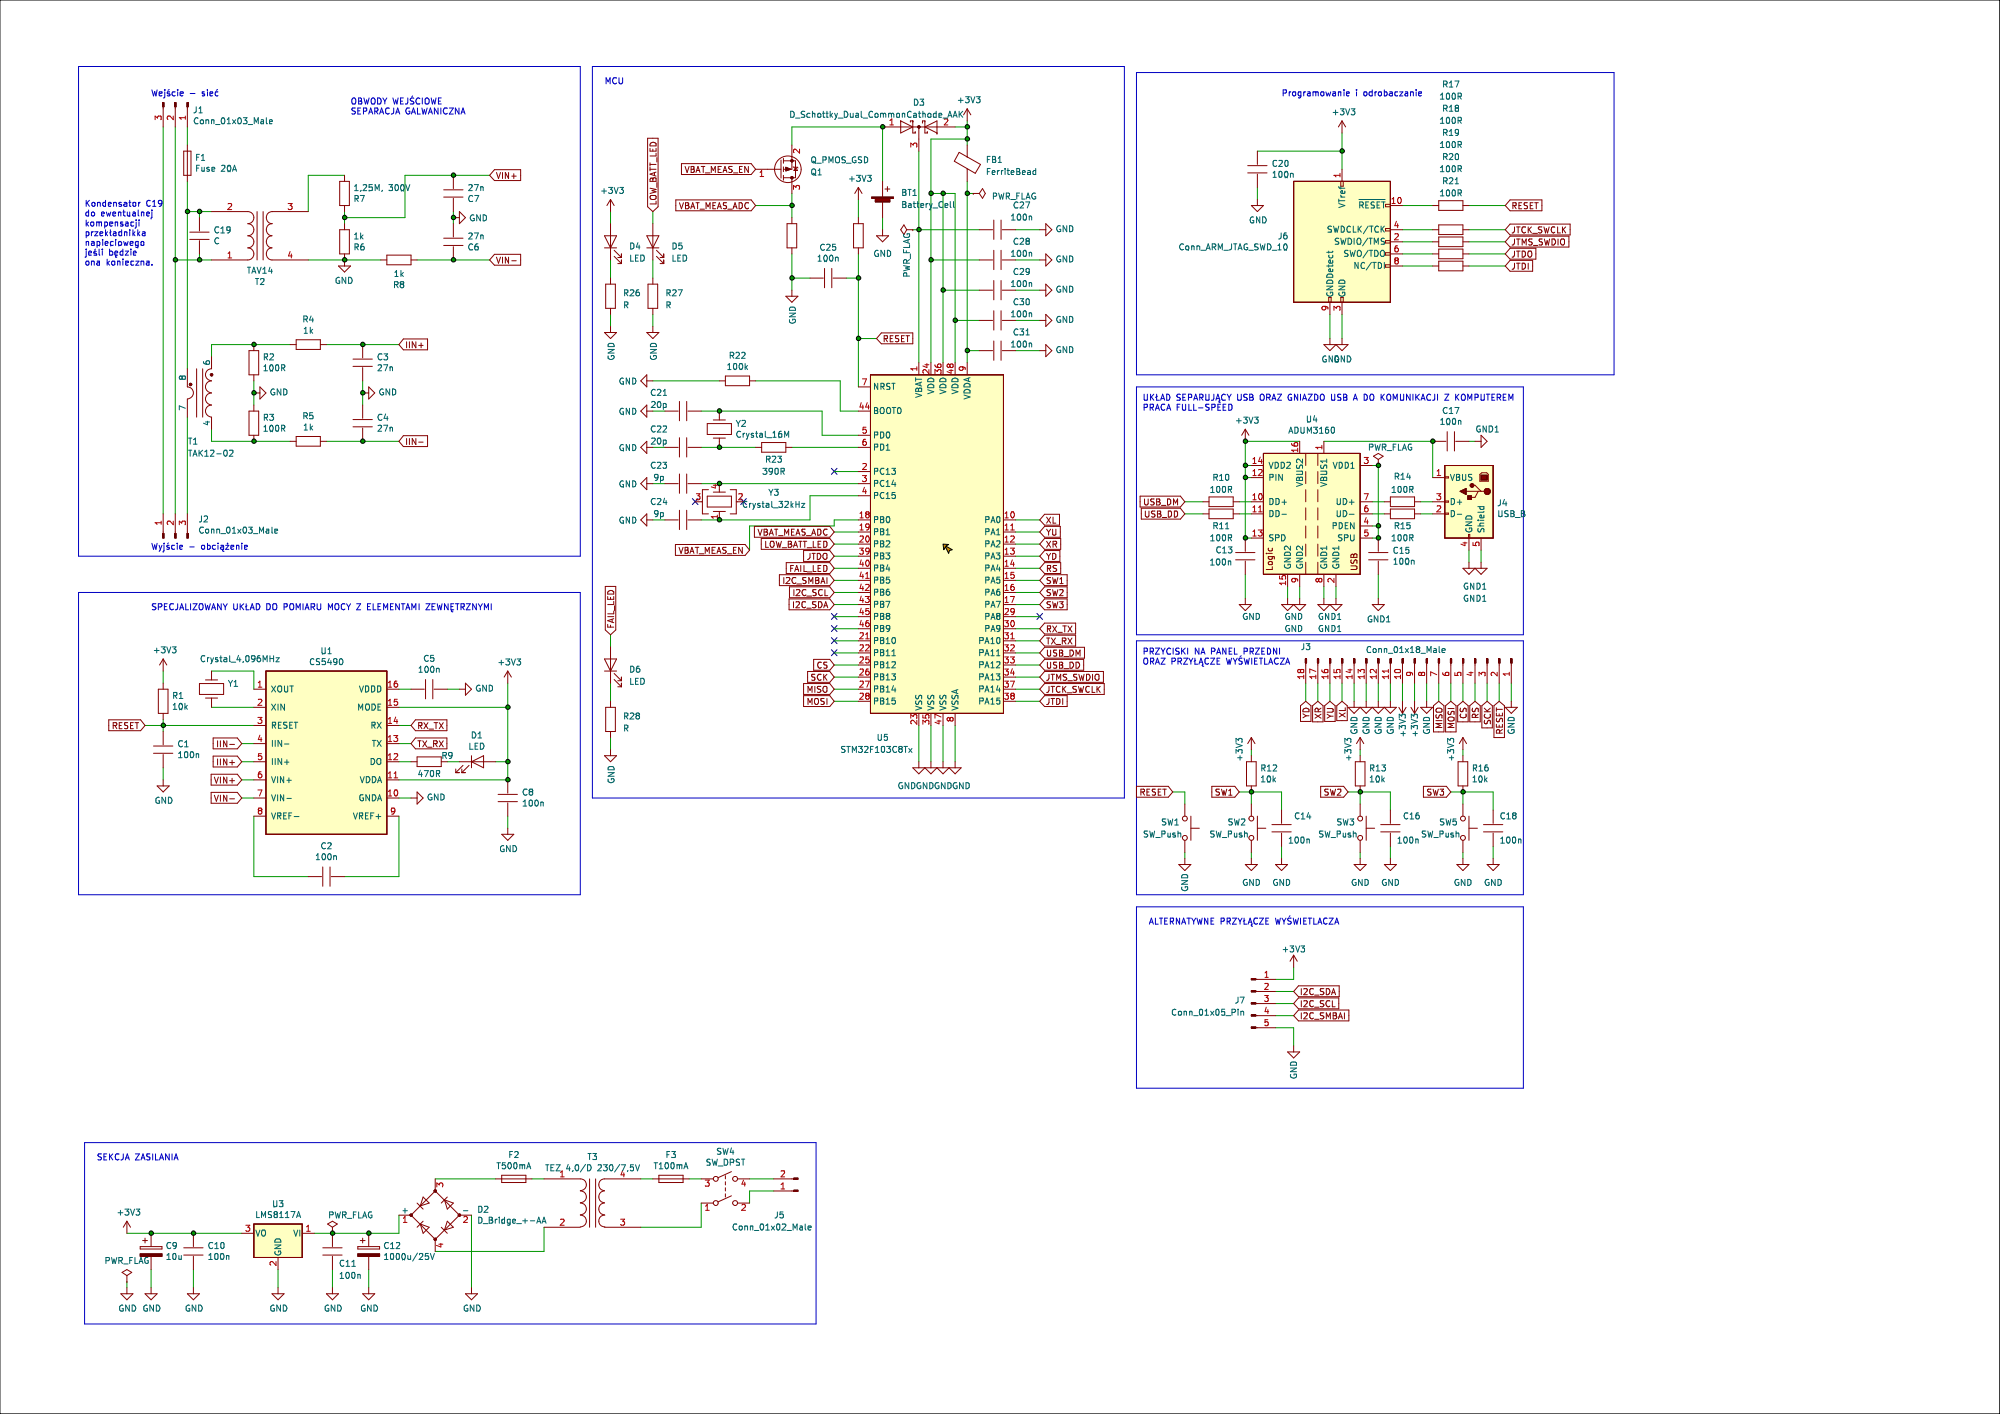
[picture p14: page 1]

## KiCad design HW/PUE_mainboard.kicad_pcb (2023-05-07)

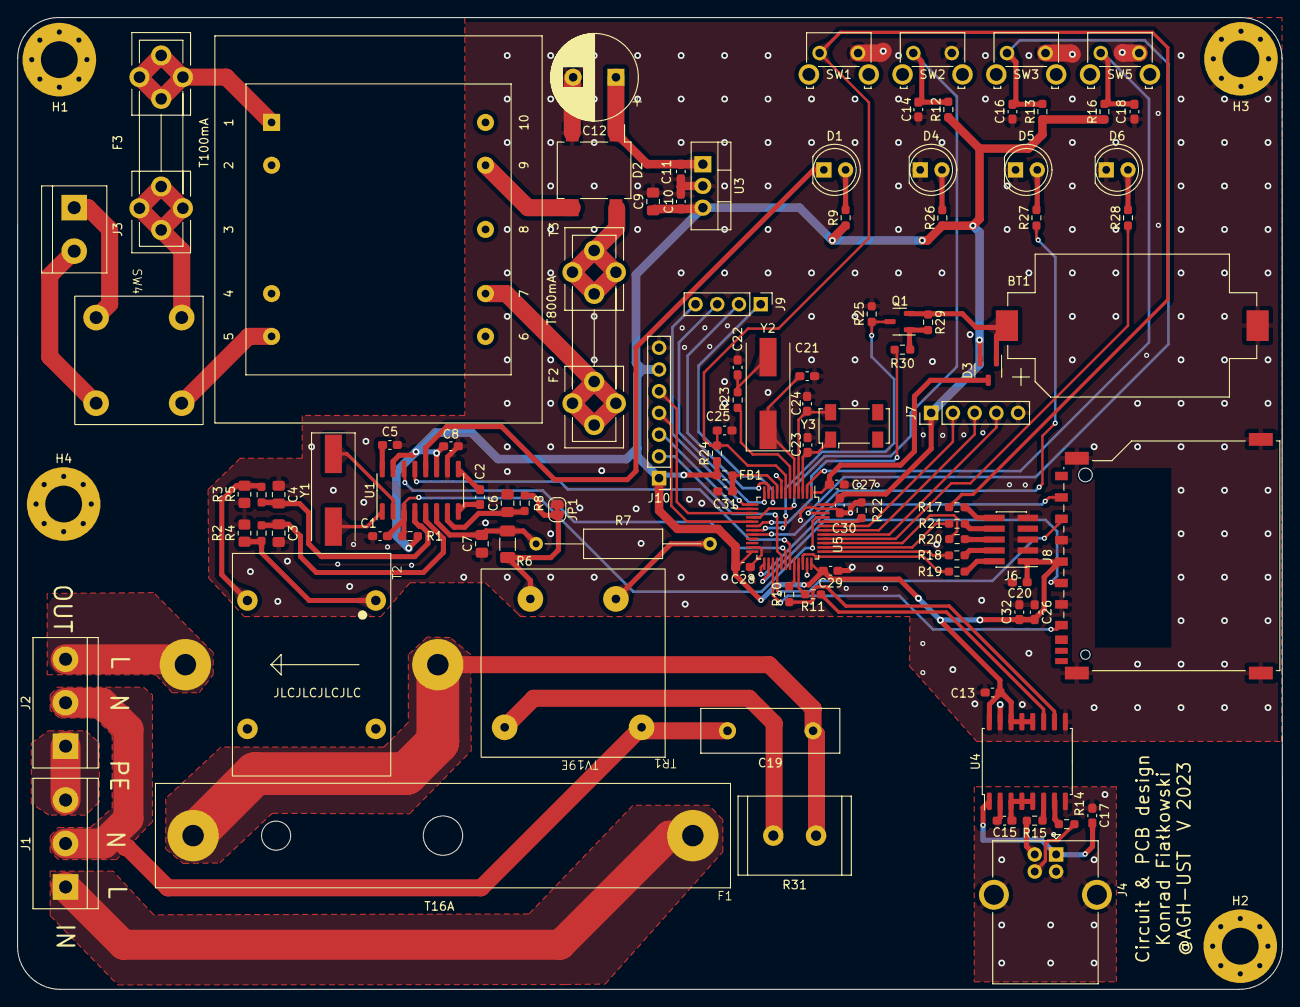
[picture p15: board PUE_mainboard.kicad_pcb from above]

Board: 2 copper layers, 147.8 x 113.6 mm, 104 parts (0 on the bottom side), 91 nets.

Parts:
BT1: Battery_Cell; BatteryHolder_Keystone_1060_1x2032
C1, C2, C5, C8, C10, C11, C13, C14, C15, C16, C17, C18, C20, C25, C26, C27, C28, C29, C30, C31: 100n; C_0603_1608Metric_Pad1.08x0.95mm_HandSolder
C3, C4, C6, C7: 27n; C_0805_2012Metric_Pad1.18x1.45mm_HandSolder
C9: 10u; C_0805_2012Metric_Pad1.18x1.45mm_HandSolder
C12: 1000u/25V; CP_Radial_D10.0mm_P5.00mm
C19: C; C_Disc_D16.0mm_W5.0mm_P10.00mm
C21, C22: 18p; C_0603_1608Metric_Pad1.08x0.95mm_HandSolder
C23, C24: 12,5p; C_0603_1608Metric_Pad1.08x0.95mm_HandSolder
C32: 1u; C_0603_1608Metric_Pad1.08x0.95mm_HandSolder
D1, D4, D5, D6: LED; LED_D5.0mm
D2: D_Bridge_+-AA; Diode_Bridge_Vishay_DFS
D3: D_Schottky_Dual_CommonCathode_AAK; SOT-23-3
F1: Fuse 20A; BK2-S-4201-1-R
F2: T500mA; Fuseholder5x20_horiz_open_universal_Type-III
F3: T100mA; Fuseholder5x20_horiz_open_universal_Type-III
FB1: FerriteBead; R_0603_1608Metric_Pad0.98x0.95mm_HandSolder
H1, H2, H3, H4: MountingHole; MountingHole_4.3mm_M4_Pad_Via
J1, J2: Conn_01x03_Male; TerminalBlock_bornier-3_P5.08mm
J3: Conn_01x02_Male; TerminalBlock_bornier-2_P5.08mm
J4: USB_B; USB_B_OST_USB-B1HSxx_Horizontal
J6: Conn_ARM_JTAG_SWD_10; PinHeader_2x05_P1.27mm_Vertical_SMD
J7: Conn_01x05_Pin; PinHeader_1x05_P2.54mm_Vertical
J8: SD_Card; SD_TE_2041021
J9: Conn_01x04_Pin; PinHeader_1x04_P2.54mm_Vertical
J10: Conn_01x07_Pin; PinHeader_1x07_P2.54mm_Vertical
JP1: Jumper_2_Bridged; SolderJumper-2_P1.3mm_Bridged_RoundedPad1.0x1.5mm
Q1: Q_PMOS_GSD; SOT-23-3
R1, R12, R13, R16, R22, R24, R25, R29: 10k; R_0603_1608Metric_Pad0.98x0.95mm_HandSolder
R2, R3: 25R; R_0805_2012Metric_Pad1.20x1.40mm_HandSolder
R4, R5, R8: 1k; R_0603_1608Metric_Pad0.98x0.95mm_HandSolder
R6: 50R; R_1206_3216Metric_Pad1.30x1.75mm_HandSolder
R7: 450R, 0,25W; R_Axial_DIN0309_L9.0mm_D3.2mm_P20.32mm_Horizontal
R9: 470R; R_0603_1608Metric_Pad0.98x0.95mm_HandSolder
R10, R11, R14, R15: 24R; R_0603_1608Metric_Pad0.98x0.95mm_HandSolder
R17, R18, R19, R20, R21, R30: 100R; R_0603_1608Metric_Pad0.98x0.95mm_HandSolder
R23: 390R; R_0603_1608Metric_Pad0.98x0.95mm_HandSolder
R26, R27, R28: 33R; R_0603_1608Metric_Pad0.98x0.95mm_HandSolder
R31: 100k; 300V; R_Radial_Power_L13.0mm_W9.0mm_P5.00mm
SW1, SW2, SW3, SW5: SW_Push; SW_SPST_Omron_B3F-315x_Angled
SW4: SW_DPST; mains_switch
T2: TA14Z-400
T3: TEZ 6,0/D 230/7,5V; Transformer_Breve_TEZ-38x45
TR1: TV19E
U1: CS5490; SOIC-16_3.9x9.9mm_P1.27mm
U3: LMS8117A; TO-220-3_Vertical
U4: ADUM3160; SOIC-16W_7.5x10.3mm_P1.27mm
U5: STM32F103C8Tx; LQFP-48_7x7mm_P0.5mm
Y1: Crystal_4,096MHz; Crystal_SMD_HC49-SD
Y2: Crystal_16M; Crystal_SMD_HC49-SD
Y3: Crystal_32kHz; Crystal_SMD_Abracon_ABS25-4Pin_8.0x3.8mm

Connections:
+3V3: C8.2, C9.1, C10.1, C13.2, C20.1, C26.2, C28.2, C29.2, C30.2, C32.2, D3.2 (A), FB1.1, J6.1 (VTref), J7.1, J8.4 (VDD), J10.1, J10.6, R1.2, R9.1, R12.1, R13.1, R16.1, R24.2, R26.1, U1.11 (VDDA), U1.15 (MODE), U3.3 (VO), U4.12 (PIN), U4.13 (SPD), U4.14 (VDD2), U4.16 (VBUS2), U5.24 (VDD), U5.36 (VDD), U5.48 (VDD)
DC: J10.2, U5.29 (PA8)
FAIL_LED: R28.1, U5.40 (PB4)
GND: BT1.2 (-), C1.1, C3.2, C4.1, C5.1, C6.2, C7.1, C8.1, C9.2, C10.2, C11.2, C12.2, C13.1, C14.2, C16.2, C18.2, C20.2, C21.2, C22.2, C23.2, C24.2, C25.2, C26.1, C27.1, C28.1, C29.1, C30.1, C31.1, C32.1, D2.2 (-), D4.1 (K), D5.1 (K), D6.1 (K), H3.1, J6.3 (GND), J6.5 (GND), J6.9 (GNDDetect), J7.5, J8.3 (VSS), J8.6 (VSS), J8.12 (SHELL1), J10.7, JP1.1 (A), R2.2, R3.1, R22.2, R25.1, SW1.2, SW2.2, SW3.2, SW5.2, U1.10 (GNDA), U3.2 (GND), U4.9 (GND2), U4.15 (GND2), U5.8 (VSSA), U5.23 (VSS), U5.35 (VSS), U5.47 (VSS)
GND1: C15.1, C17.1, J4.4 (GND), J4.5 (Shield), U4.2 (GND1), U4.8 (GND1)
I2C_SCL: J7.3, U5.42 (PB6)
I2C_SDA: J7.2, U5.43 (PB7)
I2C_SMBAI: J7.4, U5.41 (PB5)
IIN+: C3.1, R4.1, U1.5 (IIN+)
IIN-: C4.2, R5.1, U1.4 (IIN-)
JTCK_SWCLK: R18.1, U5.37 (PA14)
JTDI: R21.1, U5.38 (PA15)
JTDO: R20.1, U5.39 (PB3)
JTMS_SWDIO: R19.1, U5.34 (PA13)
LOW_BATT_LED: R27.1, U5.20 (PB2)
unnamed: BT1.1 (+), D3.1 (A), Q1.2 (S), R29.1
unnamed: C19.1, F1.2, R31.1, T2.6
unnamed: C22.1, R23.2, Y2.2
unnamed: D1.2 (A), R9.2
unnamed: D1.1 (K), U1.12 (DO)
unnamed: C11.1, C12.1, D2.1 (+), U3.1 (VI)
unnamed: D2.3, T3.9
unnamed: D2.4, F2.2
unnamed: C27.2, D3.3 (K), U5.1 (VBAT)
unnamed: D4.2 (A), R26.2
unnamed: D5.2 (A), R27.2
unnamed: D6.2 (A), R28.2
unnamed: F2.1, T3.7
unnamed: F3.1, SW4.1
unnamed: F3.2, T3.1
unnamed: F1.1, J1.1
unnamed: C19.2, J1.2, J2.2, TR1.5
unnamed: J1.3, J2.1
unnamed: J2.3, T2.5
unnamed: J3.1, SW4.2
unnamed: J3.2, SW4.4
unnamed: J4.3 (D+), R14.1
unnamed: J4.2 (D-), R15.1
unnamed: C17.2, J4.1 (VBUS), U4.1 (VBUS1)
unnamed: J6.8 (NC/TDI), R21.2
unnamed: J6.4 (SWDCLK/TCK), R18.2
unnamed: J6.2 (SWDIO/TMS), R19.2
unnamed: J6.6 (SWO/TDO), R20.2
unnamed: J6.10 (~RESET), R17.2
unnamed: JP1.2 (B), R6.1, R8.2, TR1.9
unnamed: Q1.1 (G), R29.2, R30.2
unnamed: R2.1, R4.2, T2.1
unnamed: R3.2, R5.2, T2.2
unnamed: R7.2, TR1.7
unnamed: R31.2, TR1.1
unnamed: SW4.3, T3.5
unnamed: C5.2, U1.16 (VDDD)
unnamed: C2.1, U1.9 (VREF+)
unnamed: C2.2, U1.8 (VREF-)
unnamed: U1.2 (XIN), Y1.1
unnamed: U1.1 (XOUT), Y1.2
unnamed: R10.1, U4.10 (DD+)
unnamed: R11.1, U4.11 (DD-)
unnamed: C15.2, U4.3 (VDD1), U4.4 (PDEN), U4.5 (SPU)
unnamed: R14.2, U4.7 (UD+)
unnamed: R15.2, U4.6 (UD-)
unnamed: R22.1, U5.44 (BOOT0)
unnamed: C23.1, U5.3 (PC14), Y3.1
unnamed: C24.1, U5.4 (PC15), Y3.4
unnamed: C21.1, U5.5 (PD0), Y2.1
unnamed: R23.1, U5.6 (PD1)
unnamed: C31.2, FB1.2, U5.9 (VDDA)
RES: J10.3, U5.14 (PA4)
RESET: C25.1, R17.1, R24.1, SW1.1, U5.7 (NRST)
RESET_METER: C1.2, R1.1, U1.3 (RESET), U5.45 (PB8)
RX_TX: U1.14 (RX), U5.30 (PA9)
SPI1_MOSI: J10.4, U5.17 (PA7)
SPI1_SCK: J10.5, U5.15 (PA5)
SPI2_CS: J8.1 (CD/DAT3), U5.25 (PB12)
SPI2_MISO: J8.7 (DAT0), U5.27 (PB14)
SPI2_MOSI: J8.2 (CMD), U5.28 (PB15)
SPI2_SCK: J8.5 (CLK), U5.26 (PB13)
SW1: C14.1, R12.2, SW2.1, U5.16 (PA6)
SW2: C16.1, R13.2, SW3.1, U5.46 (PB9)
SW3: C18.1, R16.2, SW5.1, U5.2 (PC13)
TX_RX: U1.13 (TX), U5.31 (PA10)
USB_DD: R11.2, U5.33 (PA12)
USB_DM: R10.2, U5.32 (PA11)
VBAT_MEAS_ADC: Q1.3 (D), R25.2, U5.19 (PB1)
VBAT_MEAS_EN: R30.1, U5.18 (PB0)
VIN+: C7.2, R6.2, R7.1, U1.6 (VIN+)
VIN-: C6.1, R8.1, U1.7 (VIN-)
XL: J9.1, U5.10 (PA0)
XR: J9.3, U5.12 (PA2)
YD: J9.4, U5.13 (PA3)
YU: J9.2, U5.11 (PA1)

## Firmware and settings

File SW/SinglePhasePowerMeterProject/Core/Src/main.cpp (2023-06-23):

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
/* Includes ------------------------------------------------------------------*/
#include "main.h"
#include "spi.h"
#include "usart.h"
#include "usb_device.h"
#include "gpio.h"

/* USER CODE BEGIN Includes */
#include "buttons.h"
#include "state_displays.h"
#include "st7789.h"
#include "menu.h"
#include "string.h"
#include "CS5490.h"
#include "usbd_cdc_if.h"
/* USER CODE END Includes */

/* USER CODE BEGIN PM */
#ifndef min
#define min(a,b) (((a) < (b)) ? (a) : (b))
#endif
/* USER CODE END PM */


/* USER CODE BEGIN PV */
uint32_t cnt = 0;
char outputAppData[100];
CS5490 powerMeter(&huart1);
/* USER CODE END PV */

void SystemClock_Config(void);
/* USER CODE BEGIN 0 */
void MeasurementTask()
{
	powerMeter.ReadMeasurements();
	float *data = powerMeter.GetMeasurements();
	if(strcmp(GetCurrentNode()->name, "MEAS_1") == 0)
	{
		stateMeasurementsP1UpdateDisplay(data[1],data[0],data[2]);

	}
	else if(strcmp(GetCurrentNode()->name, "MEAS_2") == 0)
	{
		stateMeasurementsP2UpdateDisplay(data[3],data[4],data[5]);
	}

	sprintf(outputAppData, "U=%06.2f;I=%05.2f;PF=%06.2f;P=%06.1f;Q=%06.1f;S=%06.1f;\n",min(data[1], 999.99), min(data[0], 99.99),
			min(data[2], 100.00), min(data[3], 9999.9), min(data[4], 9999.9), min(data[5], 9999.9));
	sendOutputData(outputAppData);
}
/* USER CODE END 0 */

/**
  * @brief  The application entry point.
  * @retval int
  */
int main(void)
{
  /* MCU Configuration--------------------------------------------------------*/

  /* Reset of all peripherals, Initializes the Flash interface and the Systick. */
  HAL_Init();

  /* Configure the system clock */
  SystemClock_Config();

  /* Initialize all configured peripherals */
  MX_GPIO_Init();
  MX_SPI1_Init();
  MX_USB_DEVICE_Init();
  MX_USART1_UART_Init();
  /* USER CODE BEGIN 2 */
  powerMeter.Reset();
  ST7789_Init();
  ButtonsInit();
  MenuInit();
  powerMeter.UART_SetBaudrate();
  powerMeter.SetHPFilter();
  /* USER CODE END 2 */

  /* Infinite loop */
  /* USER CODE BEGIN WHILE */
  while (1)
  {

	  if(cnt == 500)
	  	  {
	  		  MeasurementTask();
	  		  cnt = 0;
	  	  }
	  	  CheckButtons();
	  	  HAL_Delay(1);
	  	  cnt++;

    /* USER CODE END WHILE */

    /* USER CODE BEGIN 3 */
  }
  /* USER CODE END 3 */
}

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


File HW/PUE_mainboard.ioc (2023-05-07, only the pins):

Mcu.UserName=STM32F103C8Tx
PA0-WKUP.Signal=GPIO_Input
PA1.Signal=GPIO_Input
PA10.Signal=USART1_RX
PA11.Signal=USB_DM
PA12.Signal=USB_DP
PA13.Signal=SYS_JTMS-SWDIO
PA14.Signal=SYS_JTCK-SWCLK
PA15.Signal=SYS_JTDI
PA2.Signal=GPIO_Input
PA3.Signal=GPIO_Input
PA4.Signal=GPIO_Input
PA5.Signal=SPI1_SCK
PA6.Signal=GPIO_Input
PA7.Signal=SPI1_MOSI
PA8.Signal=GPIO_Output
PA9.Signal=USART1_TX
PB0.Signal=GPIO_Output
PB1.Signal=ADCx_IN9
PB12.Signal=SPI2_NSS
PB13.Signal=SPI2_SCK
PB14.Signal=SPI2_MISO
PB15.Signal=SPI2_MOSI
PB2.Signal=GPIO_Output
PB3.Signal=SYS_JTDO-TRACESWO
PB4.Signal=GPIO_Output
PB5.Signal=I2C1_SMBA
PB6.Signal=I2C1_SCL
PB7.Signal=I2C1_SDA
PB8.Signal=GPIO_Output
PB9.Signal=GPIO_Input
PC13-TAMPER-RTC.Signal=GPIO_Input
PC14-OSC32_IN.Signal=RCC_OSC32_IN
PC15-OSC32_OUT.Signal=RCC_OSC32_OUT
PD0-OSC_IN.Signal=RCC_OSC_IN
PD1-OSC_OUT.Signal=RCC_OSC_OUT

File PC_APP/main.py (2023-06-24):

from tkinter import *
from tkinter.ttk import Combobox
import matplotlib.animation as animation
from matplotlib.backends.backend_tkagg import FigureCanvasTkAgg
from GUI_Functions import *
import serial.tools.list_ports


xs = []
ys = []


measurement = Measurement(0)
fig = plt.figure()
ax = fig.add_subplot(1, 1, 1)


okno = Tk()
okno.configure(bg="white")
okno.title("Power Grid Measure")
canvas = FigureCanvasTkAgg(fig, master=okno)
canvas.get_tk_widget().grid(column=0,row=2, columnspan=25, rowspan=35, sticky=N)


label_1 = Label(okno, text='Save data to file', padx = 5, pady = 5, bg='brown', width=17, fg="white")
label_2 = Label(okno, text='P:', padx = 5, pady = 5, bg='brown', width=17, fg="white")
label_3 = Label(okno,  padx = 5, pady = 5,  width=17)
label_4 = Label(okno, text='Q:', padx = 5, pady = 5, bg='brown', width=17, fg="white")
label_5 = Label(okno,  padx = 5, pady = 5,  width=17)
label_6 = Label(okno, text='S:', padx = 5, pady = 5, bg='brown', width=17, fg="white")
label_7 = Label(okno,  padx = 5, pady = 5,  width=17)
label_8 = Label(okno, text='PF:', padx = 5, pady = 5, bg='brown', width=17, fg="white")
label_9 = Label(okno,  padx = 5, pady = 5,  width=17)
label_10 = Label(okno, text='U_RMS:', padx = 5, pady = 5, bg='brown', width=17, fg="white")
label_11 = Label(okno,  padx = 5, pady = 5,  width=17)
label_12 = Label(okno, text='I_RMS:', padx = 5, pady = 5, bg='brown', width=17, fg="white")
label_13 = Label(okno,  padx = 5, pady = 5,  width=17)
label_save_data = Label(okno, text='Saving INACTIVE', padx=5, pady=5, bg="white", fg="red")
label_14 = Label(okno, width=17, bg="white")

ports = serial.tools.list_ports.comports()
portchoosen = Combobox(okno, width = 17, textvariable = "Select port", postcommand=update_ports)
for port, desc, hwid in sorted(ports):
    temp_list = list(portchoosen['values'])
    temp_list.append(port)
    portchoosen['values'] = tuple(temp_list)
portchoosen.current(0)


buttonB = Button(okno, text='Start data acquisition', command=lambda:start_saving(measurement, label_save_data), padx=5, pady=5, height=1)
buttonC = Button(okno, text='Stop data acquisition', command=lambda:stop_saving(measurement, label_save_data), padx=5, pady=5, height=1)
buttonD = Button(okno, text='Exit', command=lambda:exit(measurement), padx=5, pady=5, bg="red", width=16, fg="white")
buttonSelect = Button(okno, text='Select port', command=lambda:select_port(measurement, portchoosen), padx=5, pady=5, bg="blue", width=16, fg="white")


label_1.grid(column=26, row=20, sticky=S)
label_2.grid(column=26, row=2, sticky=S)
label_3.grid(column=26, row=3,sticky=N)
label_4.grid(column=26, row=5,sticky=S)
label_5.grid(column=26, row=6,sticky=N)
label_6.grid(column=26, row=8,sticky=S)
label_7.grid(column=26, row=9,sticky=N)
label_8.grid(column=26, row=11,sticky=S)
label_9.grid(column=26, row=12,sticky=N)
label_10.grid(column=26, row=14,sticky=S)
label_11.grid(column=26, row=15,sticky=N)
label_12.grid(column=26, row=17,sticky=S)
label_13.grid(column=26, row=18,sticky=N)
buttonD.grid(column=26, row = 26, sticky=S)
portchoosen.grid(column=15, row = 0)
buttonSelect.grid(column=16, row = 0)
ani = animation.FuncAnimation(fig, animate, fargs=(xs, ys, ax, measurement), interval=meas_period)
update_label_power(label_3, measurement)
update_label_reactive(label_5, measurement)
update_label_apparent(label_7, measurement)
update_label_power_factor(label_9, measurement)
update_label_voltage(label_11, measurement)
update_label_current(label_13, measurement)
buttonB.grid(column = 26, row =24, sticky=S)
buttonC.grid(column = 26, row =25, sticky=N)
label_save_data.grid(column=26, row=21, sticky=S)
okno.mainloop()

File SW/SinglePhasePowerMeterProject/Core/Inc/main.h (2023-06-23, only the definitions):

#define SW3_Pin GPIO_PIN_13
#define SW3_GPIO_Port GPIOC
#define Display_Reset_Pin GPIO_PIN_4
#define Display_Reset_GPIO_Port GPIOA
#define SW1_Pin GPIO_PIN_6
#define SW1_GPIO_Port GPIOA
#define Display_DC_Pin GPIO_PIN_8
#define Display_DC_GPIO_Port GPIOA
#define FAIL_LED_Pin GPIO_PIN_4
#define FAIL_LED_GPIO_Port GPIOB
#define RESET_CS5490_Pin GPIO_PIN_8
#define RESET_CS5490_GPIO_Port GPIOB
#define SW2_Pin GPIO_PIN_9
#define SW2_GPIO_Port GPIOB

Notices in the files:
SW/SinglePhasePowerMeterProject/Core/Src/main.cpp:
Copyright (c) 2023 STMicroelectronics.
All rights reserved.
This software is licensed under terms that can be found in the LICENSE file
